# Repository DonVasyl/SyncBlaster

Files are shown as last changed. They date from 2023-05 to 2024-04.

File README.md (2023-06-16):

# SyncBlaster
### MIDI input interface for TASCAM DP00x series of multitrack recorders
### based on Microchip ATtiny25/45/85 MCU

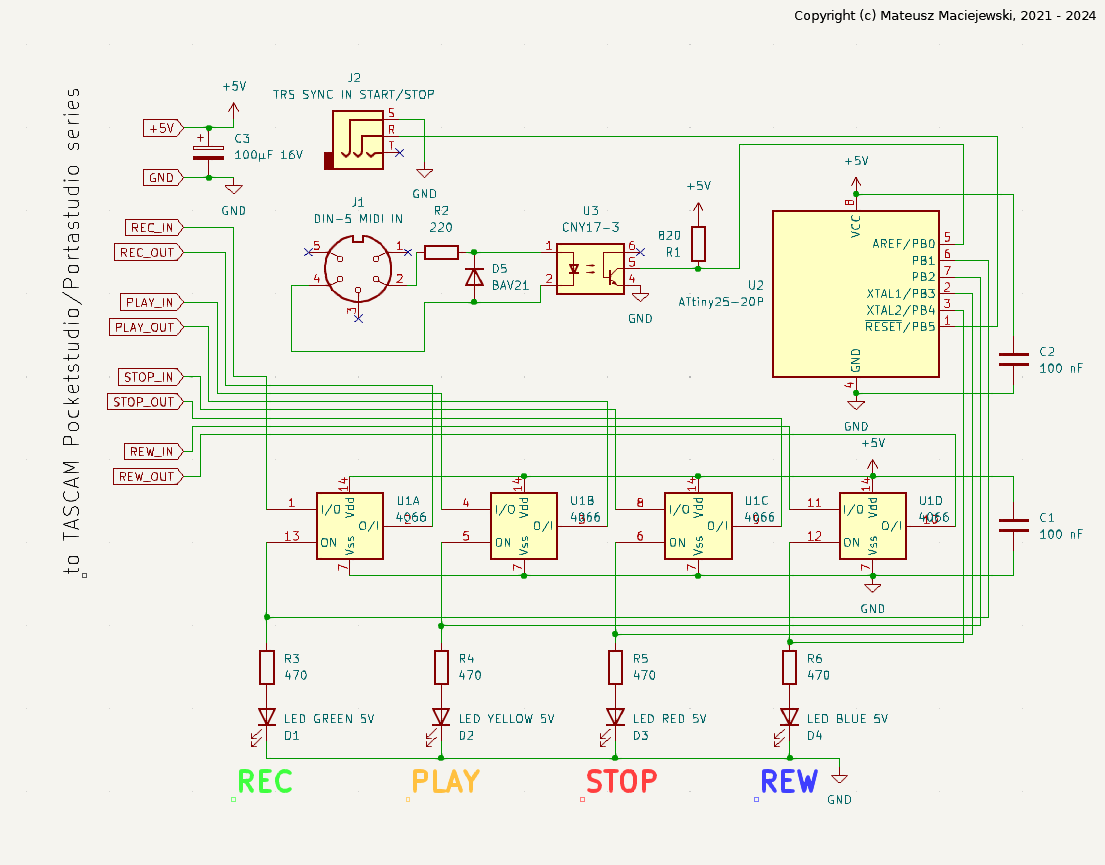
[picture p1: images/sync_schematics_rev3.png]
SyncBlaster prototype rev 3 schematics drawn in KiCAD


## Main features:
* Opto-coupled MIDI input
* Firmware image below 1024 bytes
* Recognition of SysRT (Start, Stop) and Channel (Note On, Note Off) MIDI messages
* Simulation of two key sequences: one to start recording and one to stop and rewind to zero time
* Four keys of recorder's keyboard are bypassed by external CMOS IC
* 10 wires have to be soldered to recorder's PCBs

## Operation principles:
SyncBlaster firmware operates on wide range of Microchip ATtiny microcontrollers, equiped with small amounts of memory and no UART peripheral. Instead, USI peripheral provides
partial hardware support for serial communicaton (shift register with overflow interrupt), howver time measurement must be provided externally, possibly by usage of Timer/Counter peripherals.
Four of the remaining output pins of the microcontroller are used to control CD4066 IC (quad bilateral switch), acting as recorder's keyboard bypass. Available key sequences

* Record + Play
* Stop + Rewind

are intended to initialize recording session on particular track(s) and to stop and immediately rewind virtual tape timing to zero. Automated start of recording process,
with as small latency as possible, enables recording of multiple tracks in series of takes, and eliminates manual synchronisation of recorded material between recorder's tracks.
Delay values of key sequences have been extensively tested against two main requirements:

* Quick & certain start of the recording process, right after reception of proper MIDI message;
* Certain stop and rewind operation, with higher latency latitude.

All delay values are reflecting recorder's characteristic, please note that recorder's responsiveness may vary in particular recording stages and states.

## MIDI implementation:
By default, firmware receives Channel MIDI messages on 7th channel. There are three scenarios of MIDI recording control:

1. SysRT: Start (0xFA) -> Stop (0xFC)
2. Channel: Note On (0x96 0x0C) -> Note On (0x96 0x0E)
3. Channel in single note gate mode: Note ON (0x96 0x0C) -> Note Off (0x86 0x0C)

Standard firmware builds supports scenario 1 and 2. Third scenario requires building firmware image with "singlenote" part in build target name. Please note, that scenario 3. excludes scenario 2.
This special scenario requires single note key to be kept pressed during recording process; it has been designed for usage with customized gear (i.e. with added mechanical switch(es), bypassing note key(s)).

MIDI compatibility of SyncBlaster have been verified with variety of equipment from different vendors (Yamaha, Behringer, KORG, ...).

## Missing features / TODO:
* SYNC IN digital input support (HV programmer integration required)
* Expanding range of equipment vendors & tested device types (i.e Novation, ...)

by Mateusz Maciejewski ^ TOXIC_DEATH.117

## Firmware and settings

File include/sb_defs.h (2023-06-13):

/*
 *
 * Copyright (c) Mateusz Maciejewski ^ TOXIC_DEATH.117, 2021 - 2023
 *
 */

// *** Macross ***

#define SB_MIDIUSI_REVERSE_8_BITS(iByte)  \
    (((iByte & 0x01) << 0x07) | \
     ((iByte & 0x02) << 0x05) | \
     ((iByte & 0x04) << 0x03) | \
     ((iByte & 0x08) << 0x01) | \
     ((iByte & 0x10) >> 0x01) | \
     ((iByte & 0x20) >> 0x03) | \
     ((iByte & 0x40) >> 0x05) | \
     ((iByte & 0x80) >> 0x07))

#define SB_MIDIUSI_COMPOSE_OP_AND_CHANNEL(iOp, iChannel) \
    (((iChannel & 0x01) << 0x07) | \
     ((iChannel & 0x02) << 0x05) | \
     ((iChannel & 0x04) << 0x03) | \
     ((iChannel & 0x08) << 0x01) | \
     ((iOp & 0x01) << 0x03) | \
     ((iOp & 0x02) << 0x01) | \
     ((iOp & 0x04) >> 0x01) | \
     ((iOp & 0x08) >> 0x03))

// *** MIDI ***

// MIDI SysRT

// Start
#define SB_MIDI_START                0xFA

// Continue
#define SB_MIDI_CONTINUE             0xFB

// Stop
#define SB_MIDI_STOP                 0xFC

// MIDI Channel messages

// Note On
#define SB_MIDI_NOTE_ON              0x09

// Note Off
#define SB_MIDI_NOTE_OFF             0x08

// *** I/O configuration ***

// MIDI input channel
#define SB_MIDI_IN_CHANNEL           0x06

// MIDI note to:
// * act always as [Start] when [Note On]
// * and as [Stop] when [Note Off] if SB_SINGLE_NOTE_GATE_MODE macro is defined
#define SM_MIDI_NOTE_START_GATE_STOP 0x0c

// MIDI note to act as Stop when Note On
#define SM_MIDI_NOTE_STOP            0x0e

// MCU IO configuration
#define SB_PIN_MIDI_IN               PB0
#define SB_PIN_REC                   PB1
#define SB_PIN_PLAY                  PB2
#define SB_PIN_STOP                  PB3
#define SB_PIN_REW                   PB4
// PB5 will be SYNC IN digital trigger with HVP

// *** Timigs ***

// Serial byte display
#define SB_DEBUG_DELAY_BIT_STEP      8
#define SB_DEBUG_DELAY_STOP_LIGHT    3   
#define SB_DEBUG_DELAY_STOP_SHADOW   2
#define SB_DEBUG_DELAY_EACH_STEP     8

// ** TASCAM control sequences for CD4066 IC **

// RECORD AND PLAY, RUMIA version
#define SB_TASCAM_DELAY_RECORD_PRE   2
#define SB_TASCAM_DELAY_RECORD_IN    2
#define SB_TASCAM_DELAY_RECORD_POST  0

// STOP AND REWIND, final sequence
#define SB_TASCAM_DELAY_REWIND_PRE   14
#define SB_TASCAM_DELAY_REWIND_IN    8
#define SB_TASCAM_DELAY_REWIND_POST  0

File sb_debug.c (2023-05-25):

/*
 *
 * Copyright (c) Mateusz Maciejewski ^ TOXIC_DEATH.117, 2021 - 2023
 *
 */

#include <avr/io.h>

#include <stdint.h>

#include "include/sb_defs.h"
#include "include/sb_delay.h"

void SB_DEBUG_BlinkMIDIByte(volatile uint8_t *pByte) {
	uint8_t lMask = 0x01;

	while(1) {
		if(lMask > 0x00) { // bit 0 to 7 value display sequence
			if(*pByte & lMask) {
				PORTB |= _BV(SB_PIN_REC);
 			} else {
				PORTB |= _BV(SB_PIN_STOP);
			}
			
            lMask = lMask << 1;
			SB_DELAY_Delay(SB_DEBUG_DELAY_BIT_STEP);
        } else { // stop display sequence start
			PORTB |= _BV(SB_PIN_PLAY); // turn on PLAY
			SB_DELAY_Delay(SB_DEBUG_DELAY_STOP_LIGHT);
		}

        // turn off bit value LEDs
		PORTB &= ~_BV(SB_PIN_REC);
		PORTB &= ~_BV(SB_PIN_STOP);

		if(PORTB & _BV(SB_PIN_PLAY)) { // stop display sequence continuation
			PORTB &= ~_BV(SB_PIN_PLAY); // turn off PLAY
			SB_DELAY_Delay(SB_DEBUG_DELAY_STOP_SHADOW);

			PORTB |= _BV(SB_PIN_PLAY); // turn on PLAY
			SB_DELAY_Delay(SB_DEBUG_DELAY_STOP_LIGHT);
			
            PORTB &= ~_BV(SB_PIN_PLAY); // turn off PLAY
        
			SB_DELAY_Delay(SB_DEBUG_DELAY_EACH_STEP);	
			break;
		}

		SB_DELAY_Delay(SB_DEBUG_DELAY_EACH_STEP);
	}
}

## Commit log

2023-06-16 Introducing KiCAD schematics od SyncBlaster prototype board.
    [SyncBlaster_prototype.kicad_sch]
2023-06-16 Bitmap version of SyncBlaster prototype schematics.
2023-06-16 README.md schematics image.
2024-04-04 prototype_000 board schematics release 3, MIDI OUT connection fix
    [SyncBlaster_prototype.kicad_sch]
2024-04-04 Schematics image update to release 3
2024-04-04 schematics bitmap removed from code branch
